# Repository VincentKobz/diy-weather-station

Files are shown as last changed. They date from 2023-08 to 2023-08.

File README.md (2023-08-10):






# Weather Station :cloud: :sunrise_over_mountains: :rainbow:

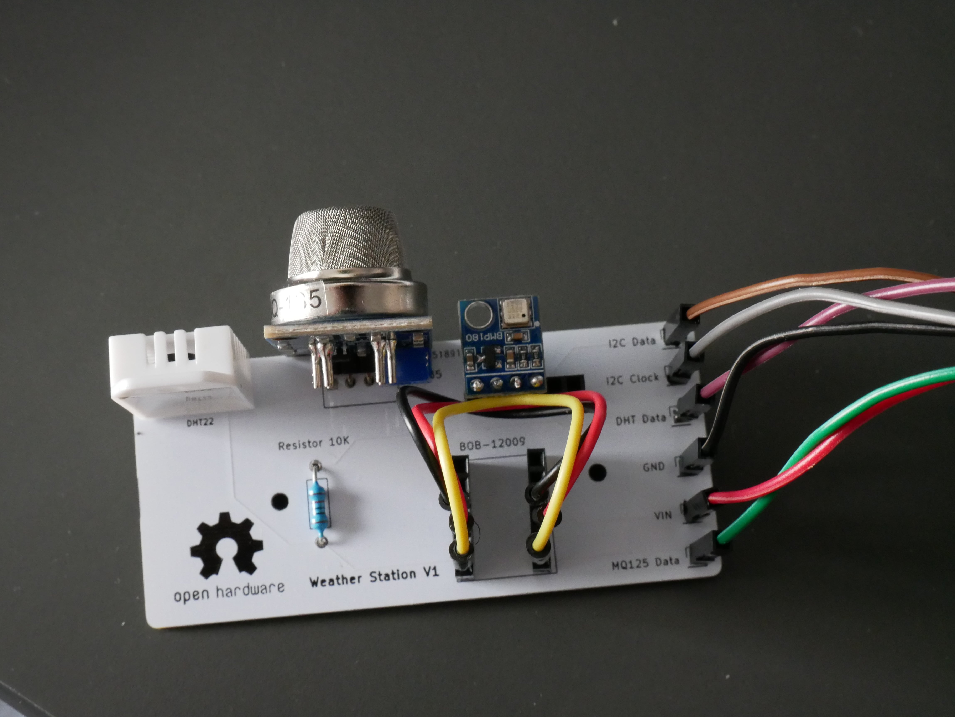
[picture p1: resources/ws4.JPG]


## Description of the project

The goal is to build from scratch a small intelligent weather station that can be connected to **IOT** networks.

It features the following sensors:
- temperature
- humidity
- pressure
- altitude
- gas (Ammonia, Nitrogen Oxide, Alcohol, Benzene, Co2, CO ...)

This GitHub repository describes the entire project, from the choice of components to the software.

## Get started

### How to setup the code

- Clone this [repository](https://github.com/VincentKobz/diy-weather-station/).

- Add this URL `https://raw.githubusercontent.com/espressif/arduino-esp32/gh-pages/package_esp32_index.json` to the additional boards manager in your IDE.

- Install the right package for your board (for me it's an [ESP32](https://github.com/espressif/arduino-esp32)).

Arduino librairies that need to be installed:
- [PubSubClient](https://pubsubclient.knolleary.net/): for MQTT protocol.
- [MQUnifiedSensor](https://github.com/miguel5612/MQSensorsLib): for MQ135 sensor.
- [Adafruit BMP085](https://github.com/adafruit/Adafruit-BMP085-Library): for BMP180 sensor.
- [DHT sensor](https://github.com/adafruit/DHT-sensor-library): for DHT22 sensor.

Inside `global_data.h`, replace `SSID`, `SSID_PWD`, `MQTT_SERVER_IP`, `MQTT_PORT`, `MQTT_DEVICE_ID` with your values.

This file contains all GPIO and sensor configuration, as well as global variables and macros.

## Bill Of Materials

All the information on **components** (BOM) and electronic schematics: [link](bom.md)

## Electronic card schematic and PCB

All the information on custom **PCB** (Printed Circuit Board): [link](kicad/kicad.md)

## Integration to home-assistant

[Home assistant](https://www.home-assistant.io/) is an open source software for home automation. I successfully connect my DIY weather station to it with an **MQTT** broker.

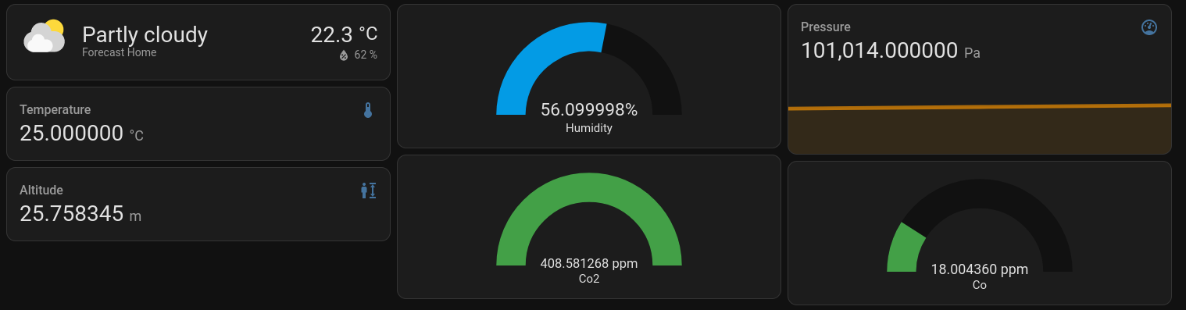
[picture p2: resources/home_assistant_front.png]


- First, the **MQTT** integration needs to be configured with broker's address, port and credentials. This can be done with the user interface.

Here is an example of the `configuration.yaml` file.

```yaml
mqtt:
  - sensor:
      # DHT22 temperature
    - name: "temperature"
      device_class: temperature
      state_topic: "esp32/out/temperature"
      unit_of_measurement: "°C"
```

- Inside the `mqtt` section, a list of sensors can be added. Here I defined the name, the [`device_class`](https://www.home-assistant.io/integrations/sensor/), the name of the topic to listen and the unit of the data.

## Photos of the Weather Station V1

The project is not finished.
I will improve it in the future, with an optimized PCB, new sensors and a 3d printed case.

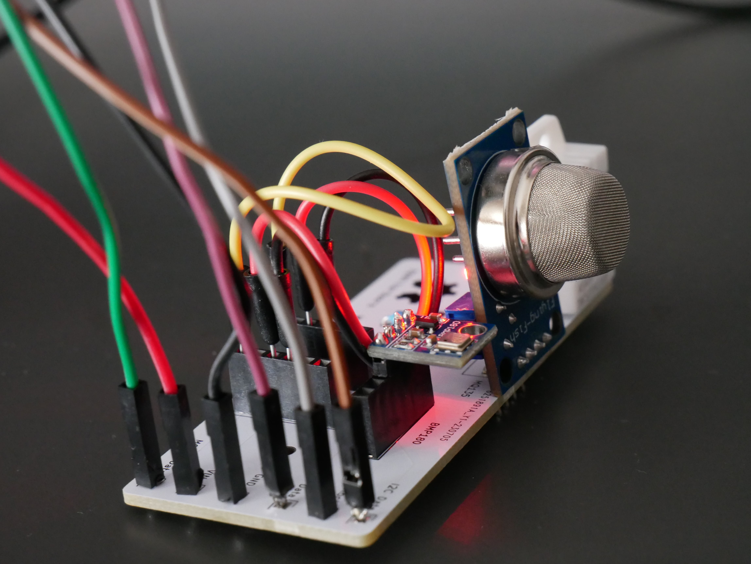
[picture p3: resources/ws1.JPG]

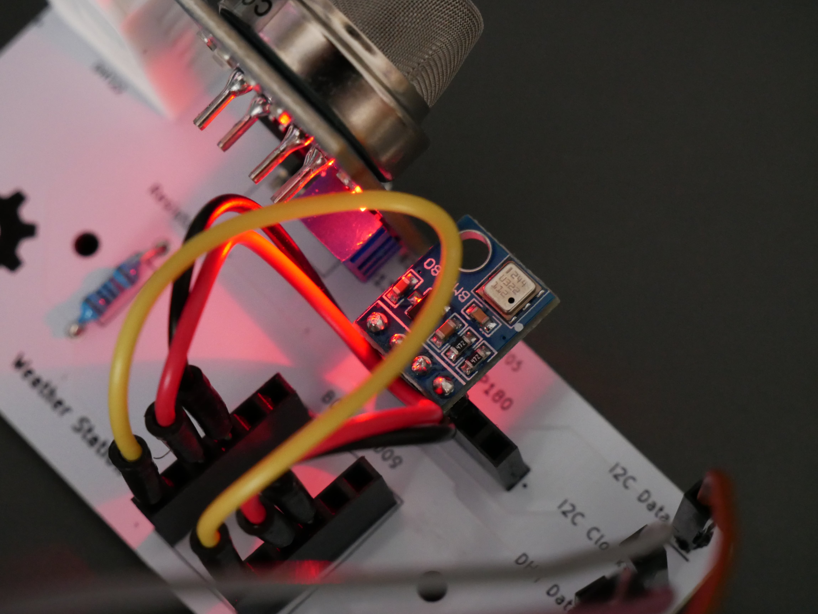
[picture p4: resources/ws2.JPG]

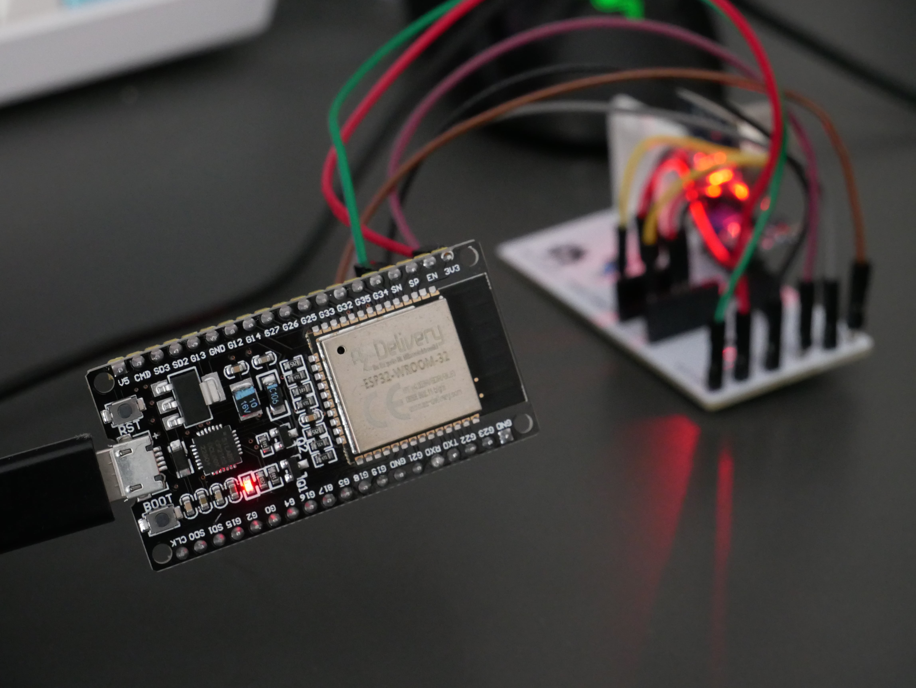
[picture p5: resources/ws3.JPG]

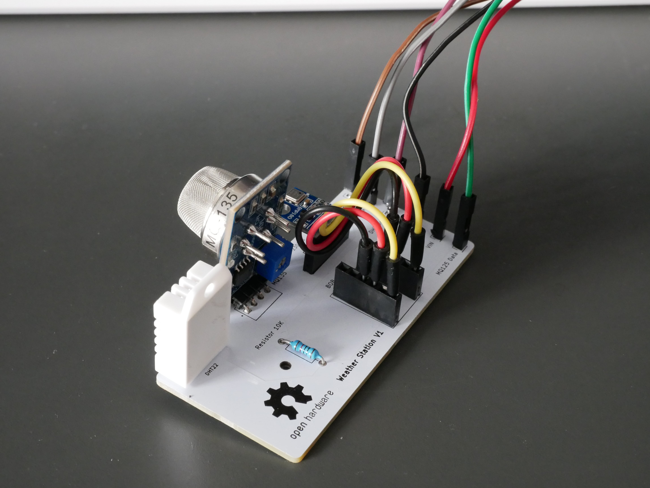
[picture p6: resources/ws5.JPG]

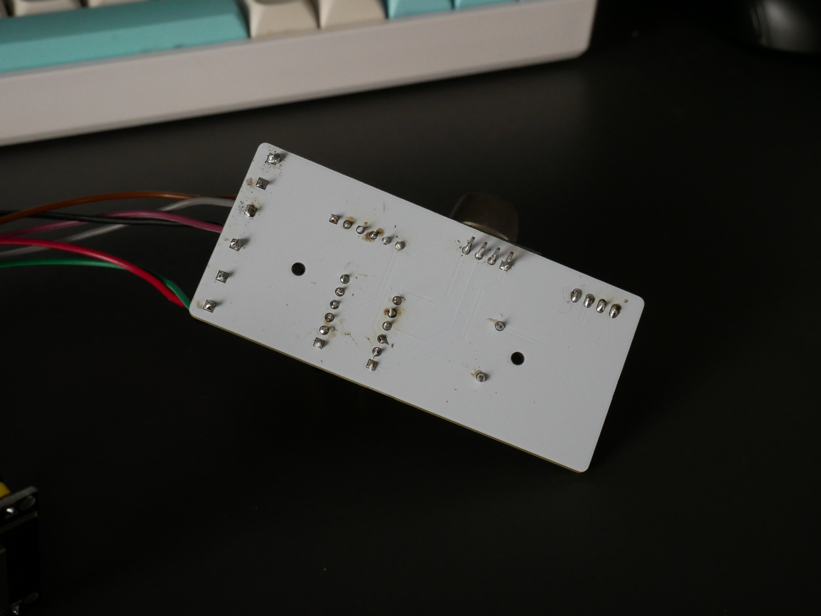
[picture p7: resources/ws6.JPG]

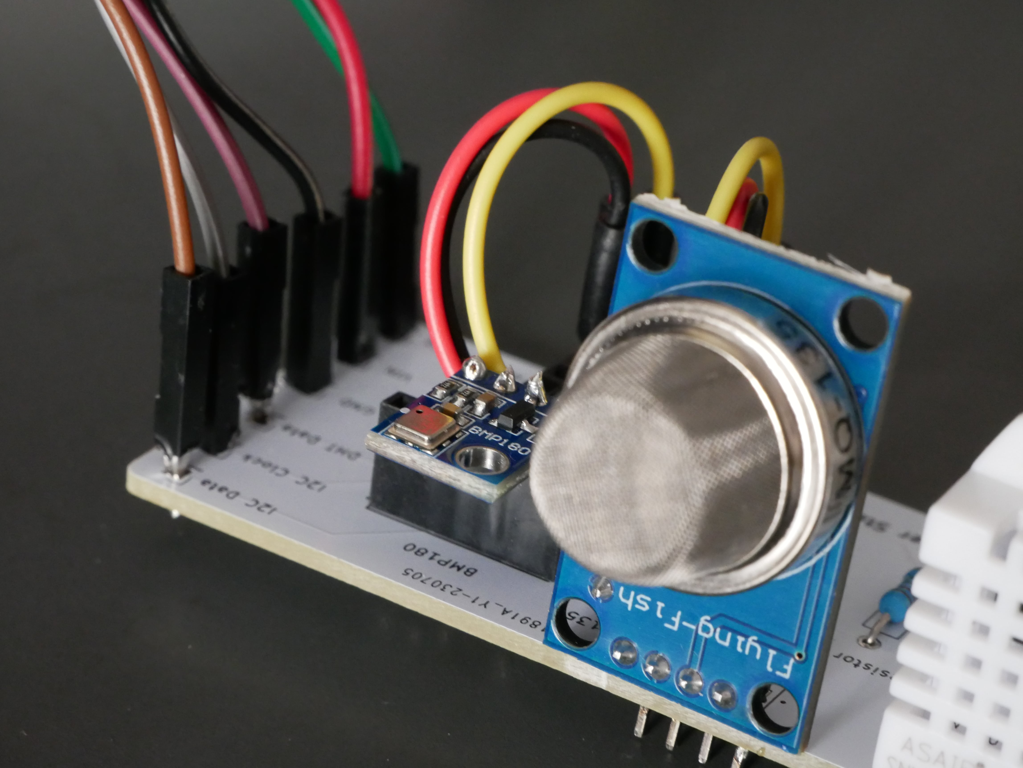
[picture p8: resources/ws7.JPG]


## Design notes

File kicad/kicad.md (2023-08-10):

# KICAD LIBRAIRIES

## Kicad project

Schematic and pcb design of my board were created using [Kicad](https://www.kicad.org/) 6.0.2.

## Footprints and symbols

Kicad project requires footprints and symbols librairies.

Here is the list of these librairies, which can be downloaded from [SnapEDA](https://www.snapeda.com/).

- [bmp180](https://www.snapeda.com/parts/HTSW-106-07-S-S-LL/Samtec/view-part/?t=HTSW-106-07-S-S-LL)
- [bob-12009](https://www.snapeda.com/parts/BOB-12009/SparkFun/view-part/?t=bob12009)
- [dht22](https://www.snapeda.com/parts/DHT22/Aosong%20Electronics/view-part/?t=dht22)
- [mq135](https://www.snapeda.com/parts/3-641215-4/TE%20Connectivity/view-part/?t=3-641215-4)

## PCB

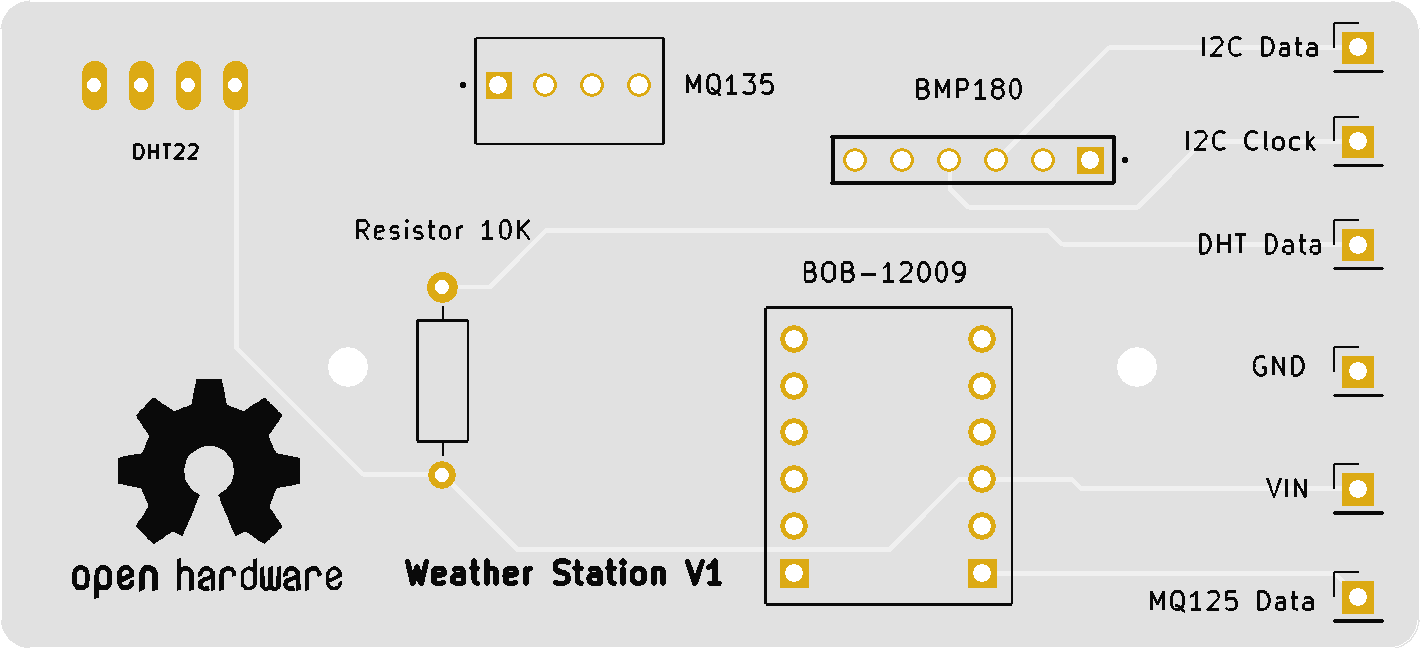
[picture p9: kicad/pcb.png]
schematic
\
Weather Station PCB V1

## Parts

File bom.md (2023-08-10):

# Bill Of Materials

## V1 - weather station

### Components

Board:
- [ESP32 Devkit v1 30 pins](https://www.espressif.com/sites/default/files/documentation/esp32_datasheet_en.pdf) - [amazon link](https://www.amazon.fr/gp/product/B07YKBY53C?psc=1)

Sensors:
- Humidity and temperature [DHT22](https://www.sparkfun.com/datasheets/Sensors/Temperature/DHT22.pdf) - [amazon link](https://www.amazon.fr/gp/product/B0BWMMBKL2?psc=1)
- Air quality / gas [MQ135](https://www.olimex.com/Products/Components/Sensors/Gas/SNS-MQ135/resources/SNS-MQ135.pdf) - [amazon link](https://www.amazon.fr/gp/product/B07CNR9K8P?psc=1)
- Raindrop [LM393](https://soldered.com/productdata/2016/01/Soldered_LM393_datasheet.pdf) - [amazon link](https://www.amazon.fr/gp/product/B017M1NJR0?psc=1)
- Air pressur [BMP280](https://cdn-shop.adafruit.com/datasheets/BST-BMP280-DS001-11.pdf) - [amazon link](https://www.amazon.fr/gp/product/B07D8TPVVY)

### Schematic

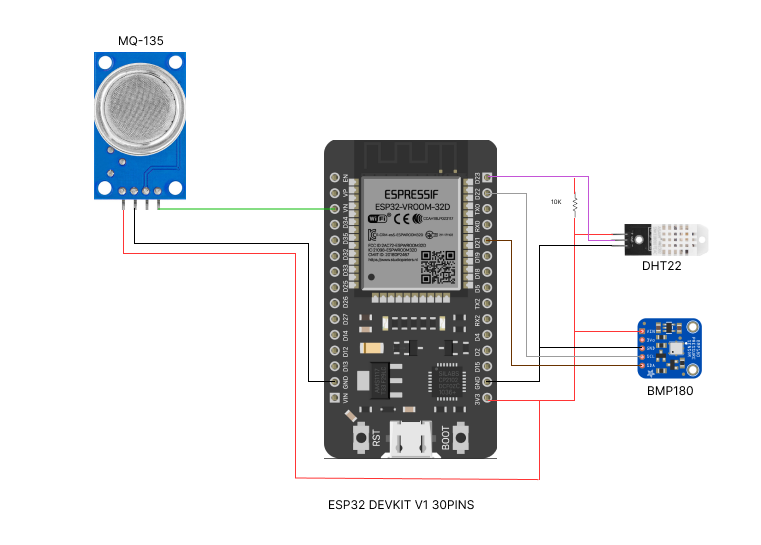
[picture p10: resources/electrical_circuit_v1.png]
schematic
\
Electrical circuit of weather-station V1

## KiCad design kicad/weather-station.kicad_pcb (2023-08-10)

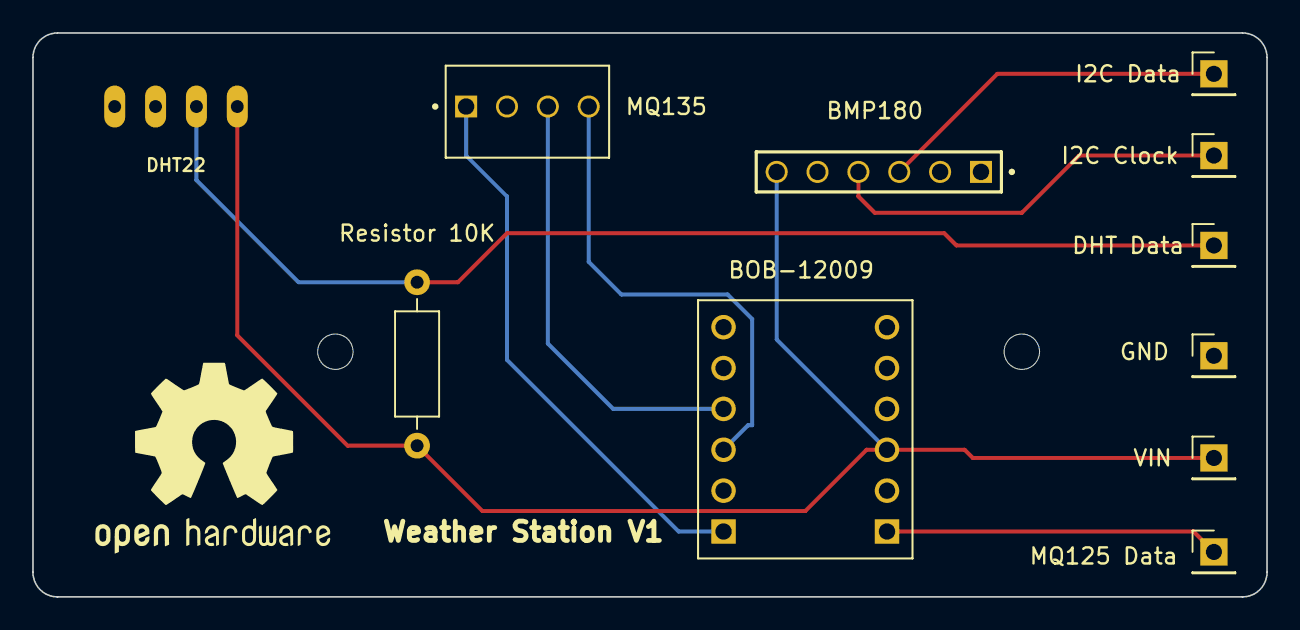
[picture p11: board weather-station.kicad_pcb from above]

Board: 2 copper layers, 76.7 x 35.1 mm, 11 parts (0 on the bottom side), 9 nets.

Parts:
BMP180: BMP180 6PIN Header; SAMTEC_HTSW-106-07-S-S-LL
BOB-12009: BOB-12009; CONV_BOB-12009
DHT22: DHT22
DHT Data: Conn_01x01_Male; PinHeader_1x01_P2.54mm_Vertical
GND: Conn_01x01_Male; PinHeader_1x01_P2.54mm_Vertical
I2C Clock, I2C Data: Conn_01x01_Male; PinHeader_1x01_P2.54mm_Vertical
MQ125 Data: Conn_01x01_Male; PinHeader_1x01_P2.54mm_Vertical
MQ135: MQ135 4PIN Header; TE_3-641215-4
Resistor 10K: 10K; R_Axial_DIN0207_L6.3mm_D2.5mm_P10.16mm_Horizontal
VIN: Conn_01x01_Male; PinHeader_1x01_P2.54mm_Vertical

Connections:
/DHT Data: DHT22.DATA, DHT Data.1, Resistor 10K.2
/GND: BMP180.05, BOB-12009.GND_2 (GND), DHT22.GND, GND.1
/GND HV: BOB-12009.GND_1 (GND), MQ135.3
/I2C Clock: BMP180.04, I2C Clock.1
/I2C Data: BMP180.03, I2C Data.1
/MQ135 Data: BOB-12009.LV1, MQ125 Data.1
/MQ135 Data HV: BOB-12009.HV1, MQ135.1
/VCC: BMP180.06, BOB-12009.LV, DHT22.VDD, Resistor 10K.1, VIN.1
/VCC HV: BOB-12009.HV, MQ135.4

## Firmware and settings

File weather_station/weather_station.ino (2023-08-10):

#include "global_data_2.h"
#include "sensor_data.h"
#include <stdlib.h>
#include <Wire.h>

// Convert float to string
char *convert_float_to_string(float value, char *string)
{
  if (!string)
  {
    string = (char *)calloc(100, sizeof(char));
  }

  if (!string)
  {
    return NULL;
  }

  // Reset string
  memset(string, '\0', 100);
  // Fill string
  snprintf(string, 100, "%f", value);

  return string;
}

// Setup MQ135
void setup_mq135()
{
  MQ135.setRegressionMethod(1);
  MQ135.init();

  // MQ135 Calibration
  float calcR0 = 0;

  for(int i = 1; i<=10; i ++)
  {
    MQ135.update();
    calcR0 += MQ135.calibrate(RATIO_MQ135_CLEAN_AIR);
  }
  MQ135.setR0(calcR0/10);
}

// Setup MQTT broker
void setup_mqtt_broker()
{
  client.setServer(MQTT_SERVER_IP, MQTT_PORT);
  client.setCallback(callback);
}

// Connect ESP32 to a Wi-Fi hotspot
void setup_wifi()
{
  // Set connection to access point
  WiFi.mode(WIFI_STA);
  char message[100];

  while (true)
  {
    // Try to connect to SSID with given password
    WiFi.begin(SSID, WIFI_PWD);

    delay(1000);
    Serial.println("Trying to connect to WiFi ...");

    // Check Wi-Fi status
    switch (WiFi.status())
    {
    case WL_CONNECTED:
      snprintf(message, 100, "Successfully connected to %s WiFi !", SSID);
      Serial.println(message);
      return;
      break;
    case WL_NO_SHIELD:
      Serial.println("No WiFi shield present !");
      return;
      break;
    case WL_CONNECT_FAILED:
      snprintf(message, 100, "Failed to connect to %s WiFi !", SSID);
      Serial.println(message);
      return;
      break;
    case WL_NO_SSID_AVAIL:
      snprintf(message, 100, "No SSID are available for %s !", SSID);
      Serial.println(message);
      return;
      break;
    case WL_IDLE_STATUS:
      Serial.println("Retry to connect to WiFi !");
      break;
    default:
      snprintf(message, 100, "Error during WiFi connection [%i] !", WiFi.status());
      Serial.println(message);
      return;
      break;
    }
  }
}

// Setup
void setup() {
  Serial.begin(9600);
  Serial.println("ESP32 ready !");
  setup_wifi();
  setup_mqtt_broker();
  dht.begin();
  setup_mq135();

  while (!bmp180.begin())
  {
    Serial.println("Bmp180 not find !");
  }
}

// Main loop
void loop() {
  // Wait for sensor
  delay(2000);

  // Check if Wi-Fi is connected
  while (WiFi.status() != WL_CONNECTED)
  {
    setup_wifi();
    delay(1000);
  }

  // [DHT22]
  get_dht22_data();

  // [MQ135]
  get_mq135_data();

  // [BMP180]
  get_bmp180_data();
}

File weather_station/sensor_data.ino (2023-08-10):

#include "mqtt_services.h"
#include "global_data.h"

// Classify CO2 ppm value to obtain air quality
void get_air_quality(float value)
{
  char *air_quality = NULL;
  if (value <= 600)
  {
    air_quality = "good";
  }
  else if (value <= 800)
  {
    air_quality = "acceptable";
  }
  else if (value <= 1000)
  {
    air_quality = "mediocre";
  }
  else
  {
    air_quality = "bad";
  }
  try_publish("esp32/out/air-quality", air_quality);
}

// Read and publish data from DHT22
void get_dht22_data()
{
  // Read humidity
  try_publish_float("esp32/out/humidity", dht.readHumidity());
  // Read temperature
  try_publish_float("esp32/out/temperature", dht.readTemperature());
}

// Read and publish data from MQ135
void get_mq135_data()
{
  MQ135.update();

  // Get CO
  MQ135.setA(605.18); MQ135.setB(-3.937);
  try_publish_float("esp32/out/co", MQ135.readSensor());

  // Get Alcohol
  MQ135.setA(77.255); MQ135.setB(-3.18);
  try_publish_float("esp32/out/alcohol", MQ135.readSensor());

  // Get co2
  MQ135.setA(110.47); MQ135.setB(-2.862);
  float co2_value = MQ135.readSensor() + 400;
  get_air_quality(co2_value);
  try_publish_float("esp32/out/co2", co2_value);

  // Get Toluen
  MQ135.setA(44.947); MQ135.setB(-3.445);
  try_publish_float("esp32/out/toluen", MQ135.readSensor());

  // Get NH4
  MQ135.setA(102.2 ); MQ135.setB(-2.473);
  try_publish_float("esp32/out/nh4", MQ135.readSensor());

  // Get Aceton
  MQ135.setA(34.668); MQ135.setB(-3.369);
  try_publish_float("esp32/out/aceton", MQ135.readSensor());
}

// Read and publish data from BMP180
void get_bmp180_data()
{
  // Air pressure
  try_publish_float("esp32/out/pressure", bmp180.readPressure());
  // Altitude (considering that sea level has pressure of 10132 Pascal)
  try_publish_float("esp32/out/altitude", bmp180.readAltitude());
}

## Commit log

2023-06-26 feat: Add basic esp32 project with WiFi connection and DHT22 sensor
2023-06-28 fix: Replace magic numbers for WiFi connection with macros
    [global_data.h, weather_station.ino]
2023-06-28 feat: Add connection to MQTT broker server
    [global_data.h, weather_station.ino]
2023-06-28 fix: Remove unnecessary mqtt connection check
    [weather_station.ino]
2023-06-28 feat: Add schematic for electrical circuit of basic weather-station
2023-06-28 update: Add electrical schematic in bom.md
2023-06-28 update: Add link to bom
2023-07-04 fix: Replace c string conversion with snprintf
    [weather_station.ino]
2023-07-06 feat: Add support of MQ135 sensor with serial print of data
2023-07-06 fix: Add function in order to convert float to string and publish MQ135 data to the MQTT broker
    [global_data.h, weather_station.ino]
2023-07-06 fix: Remove unnecessary newline and add commentary
    [weather_station.ino]
2023-07-13 fix: Increase size of electrical circuit v1 schematic
2023-07-13 feat: Add kicad project (schematic and pcb) and documentation
    [weather-station.kicad_pcb, weather-station.kicad_sch]
2023-07-13 feat: Add Kicad documentation link to README
2023-07-13 feat: Add PCB png in kicad documentation
2023-07-17 fix: Use snprintf instead of multiple serial printing
    [weather_station.ino]
2023-07-22 fix: Use snprintf for logging
    [weather_station.ino]
2023-07-22 feat: Add support of BMP180 sensor for altitude and air pressure
2023-07-22 refactor: Publish sensor data into MQTT topics
2023-08-05 fix: Add check of BMP180 sensor presence
    [weather_station.ino]
2023-08-07 update: Add sensor to the list
2023-08-09 update: Electrical circuit v1
2023-08-10 refactor: Separate mqtt and sensor services from main file
2023-08-10 fix: Add air quality function call
    [sensor_data.ino]

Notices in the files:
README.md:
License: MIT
